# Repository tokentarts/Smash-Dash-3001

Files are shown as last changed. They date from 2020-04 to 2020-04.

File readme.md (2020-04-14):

# Smash Dash 3000

_By: Summer_

Smash Dash 3000 (https://www.youtube.com/watch?v=m0qOhI8Xyro "Smash Dash 3000")

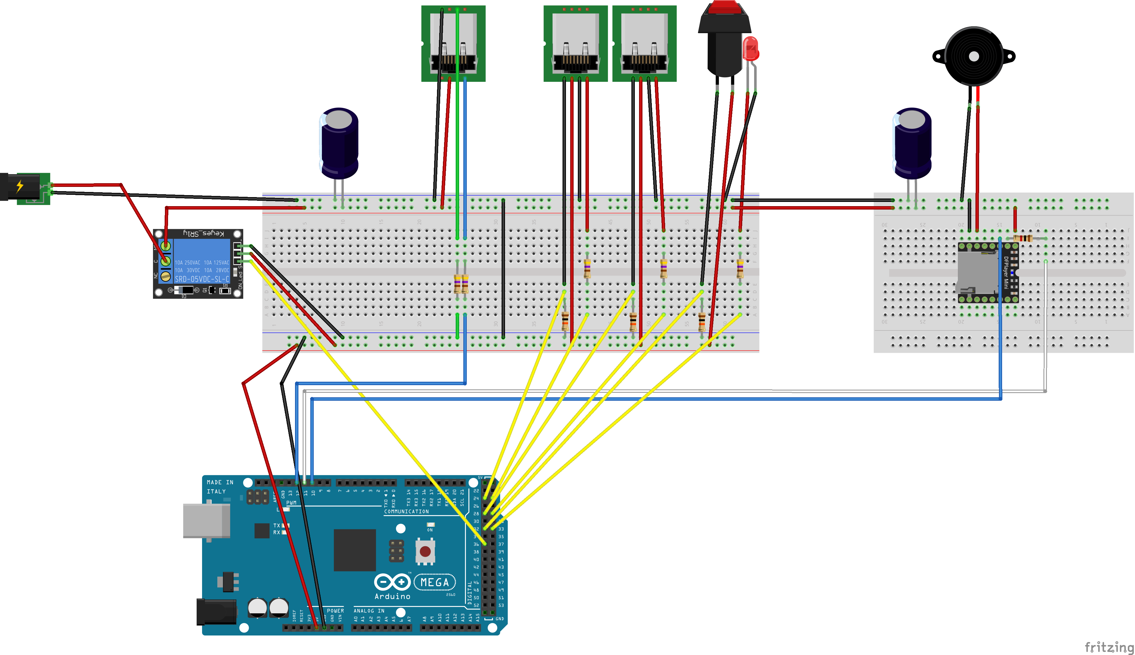
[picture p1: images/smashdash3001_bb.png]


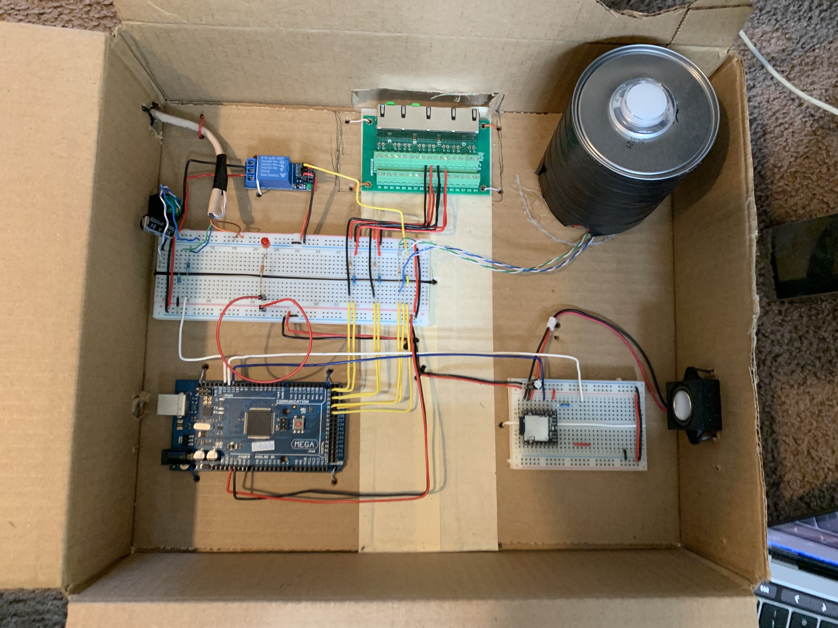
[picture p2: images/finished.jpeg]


This is a project about lights. I built an arduino based racing game involving smashing a button and racing to the end of an LED strip. There are added mechanics like gravity to make the game more exciting.

Shoutout to the inspiration for this project, [Open LED Race](https://create.arduino.cc/projecthub/gbarbarov/open-led-race-a0331a).

## Supplies

- Arduino Mega
- 5V Relay
- 5V 2.5A Power Supply
- WS2813 Led Strip 60 LED/5 Meter
- DF Player Mini
- RJ45 4-Port Breakout Board
- RJ45 Keystone (1)
- RJ45 Breakout (2)
- 1000 uF Capacitor
- 470 uF Capacitor
- 470 Ohm Resistor (5)
- 1000 Ohm Resistor
- 10k Ohm Resistor (3)
- Cardboard Box
- 3 Watt Speaker
- Pringles Can
- Empty Pill Bottle (2)
- 22 AWG Solid Wire
- Ethernet Cable
- Male RJ45 Connectors
- Breadboard
- Arcade Button (3)
- Micro SD

### Other things you'll need

- Micro SD Reader
- Wire Stripper
- RJ45 Crimper
- Soldering Iron
- Solder
- Shrinktube

## 1. Arduino and LED

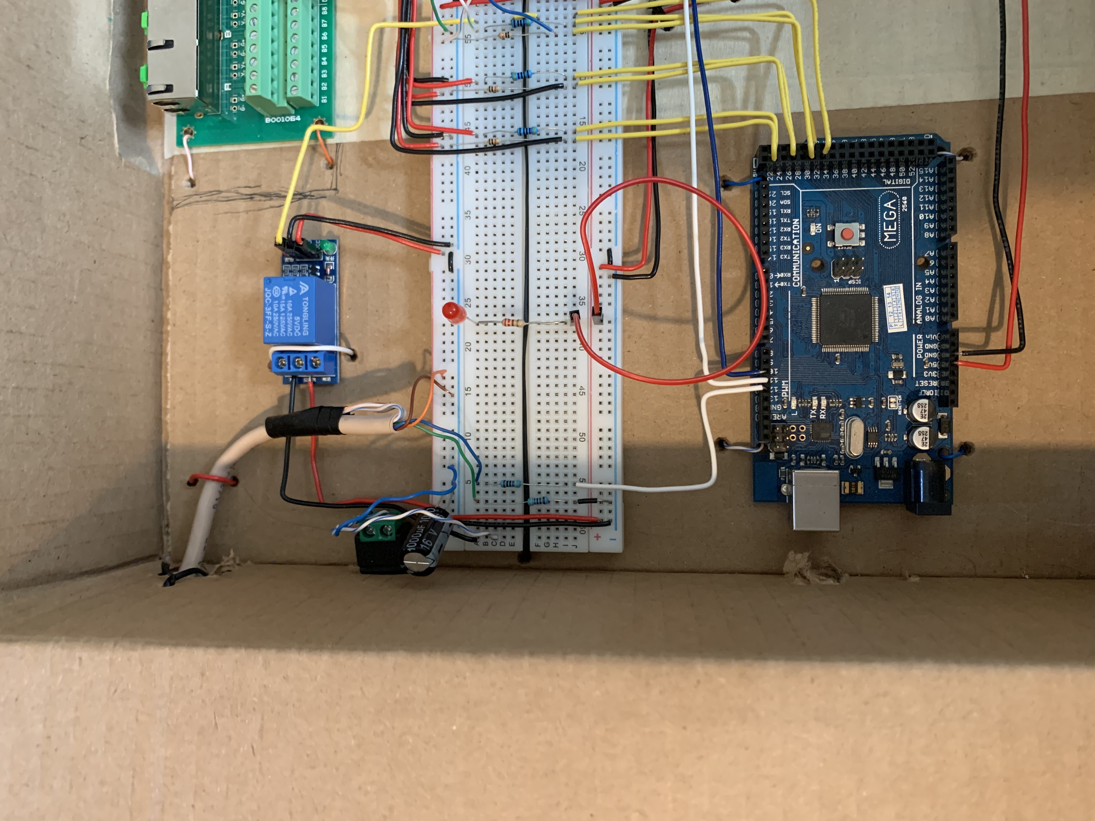
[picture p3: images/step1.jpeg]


### 1.1 Set up box

#### 1.1.1

Attach to your box: Arduino Mega, breadboard, relay, RJ45 plug, power supply plug

#### 1.1.2

Plug Arduino into breadboard (refer to wiring schematic).

#### 1.1.3

Plug relay into breadboard (refer to wiring schematic).

#### 1.1.4

RJ45 to breadboard, add resistors

Green = Back-up Data Line </br>
Blue = Data Line </br>
Orange = 5V </br>
Brown = Ground

Add a 470 Ohm resistor on both data line (refer to wiring schematic).

#### 1.1.5

Plug power supply into breadboard, add 1000 uF capacitor.

### 1.2 Set up LED strip

#### 1.2.1 Build LED extension wire

About 6-9 feet in length.

Solder wire connections.

Red (5V) = Orange </br>
Black (Ground) = Brown </br>
Yellow (Data) = Blue </br>
Green (Back-up Data) = Green

Use heat shrink.



#### 1.2.2 Tape LED wire leads

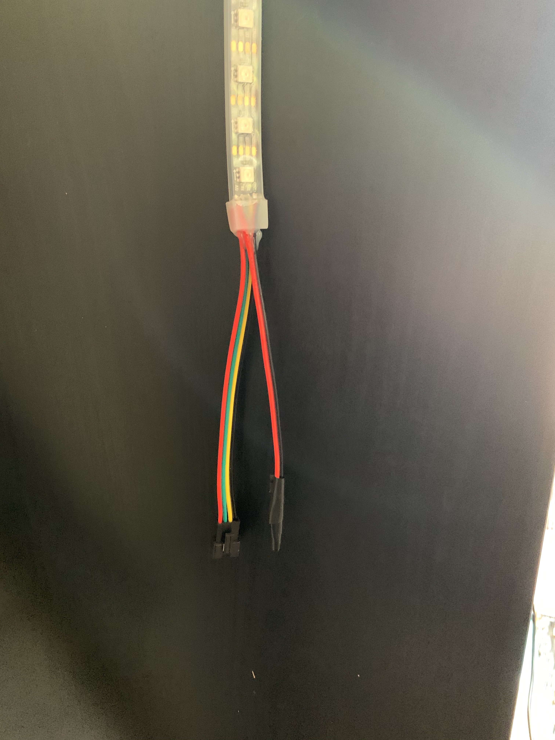
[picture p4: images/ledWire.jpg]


#### 1.2.3 Plug LED strip into RJ45 keystone.

### 1.3 Software: Turn on lights

See [`./code/step1-turnOnLights.ino`](./code/step1-turnOnLights.ino)

## Step 2: Start Button

### 2.1

Saw can half an inch inch taller than your box.

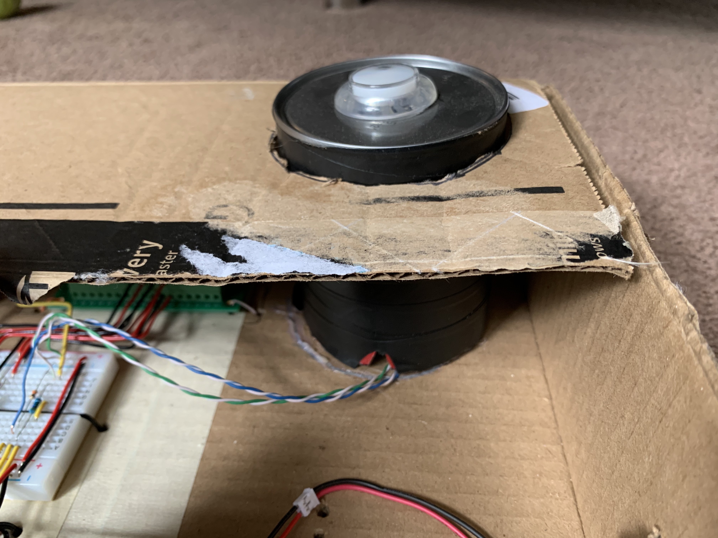
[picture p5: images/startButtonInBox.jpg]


### 2.2

Cut a hole for your arcade button.

Solder lead wires to start button.

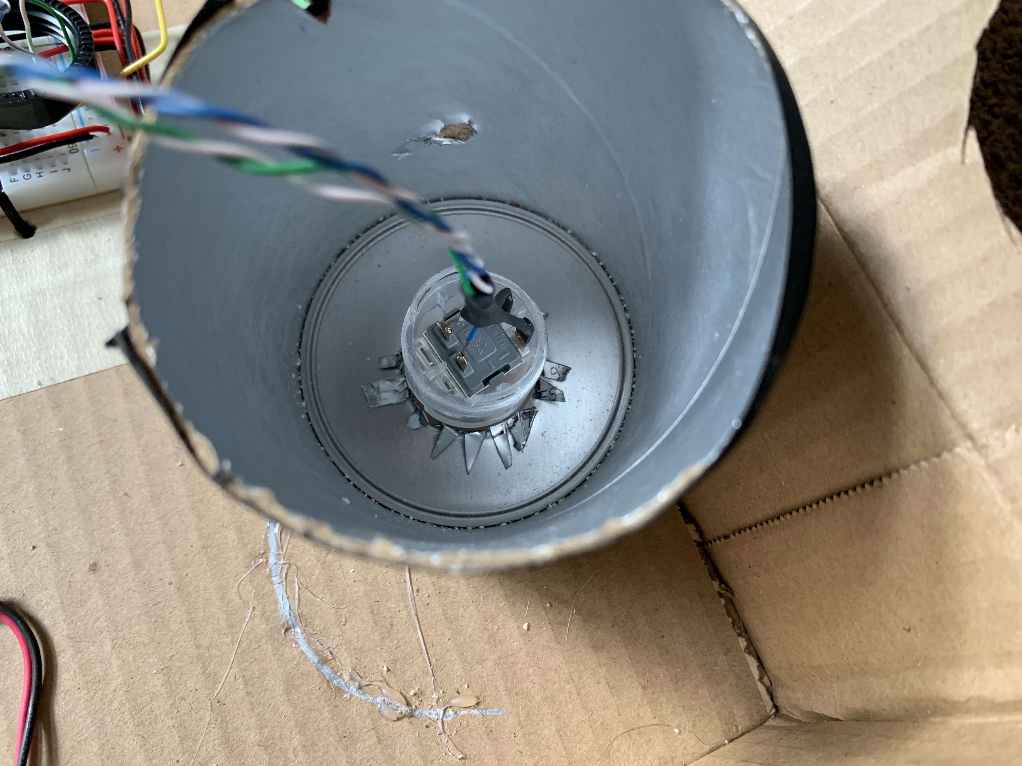
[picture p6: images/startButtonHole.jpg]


### 2.3

Connect start button lead wires to breadboard, and connect breadboard to Arduino.

Add 470 oHm resistor for LED.
Add 10k resistor for button.

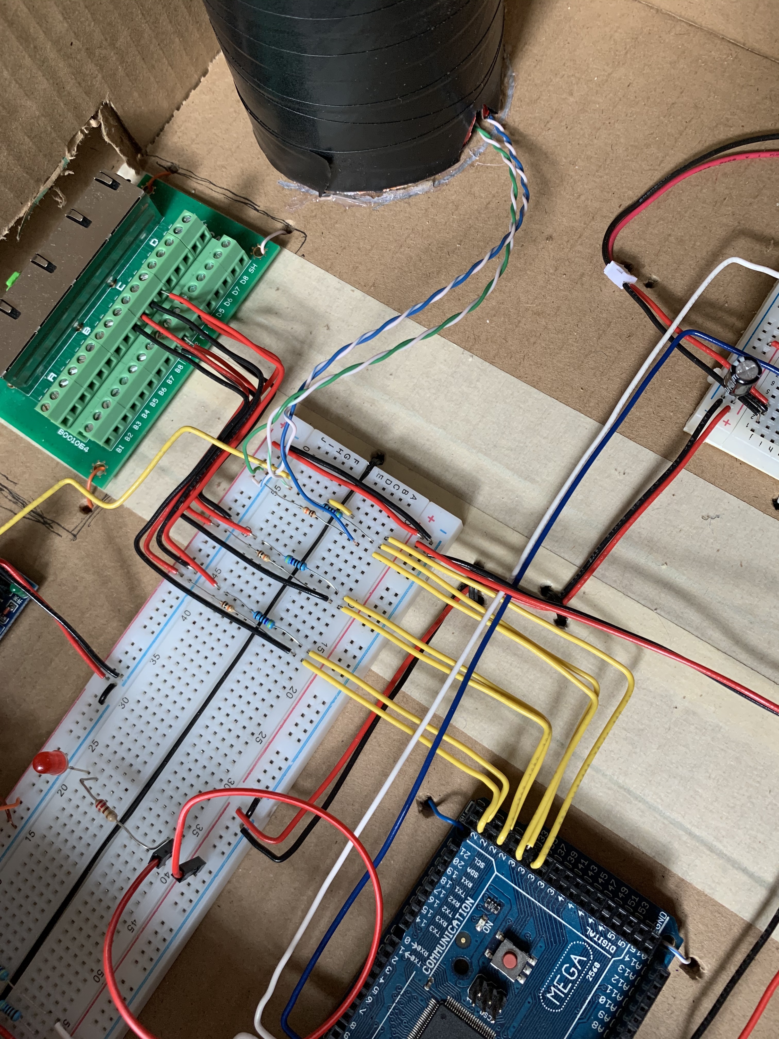
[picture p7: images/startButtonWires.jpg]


### 2.4 Software: Moving Lights

See [`./code/step2-movingLights.ino`](./code/step2-movingLights.ino)

## Step 3: Controllers

### 3.1 Connect controller breakout board to arduino

#### 3.1.1 First controller

This is the configuration for the first player controller. All wires should be connected to breakout board port `D`.

Controller breakout port wire configuration:

- Wire 1: +5 volt return from leg 2 of switch
  - Connect to an available terminal strip on breadboard
  - Connect a 10k ohm resistor from this terminal strip to ground. This ground reference helps avoid false positive readings.
- Wire 2: +5 volt going to leg 1 of switch
  - Connect to +5 volt power rail on breadboard
- Wire 3: Ground for button LED
  - Connect to -5 volt power rail on breadboard
- Wire 4: +5 volt signal for button LED
  - Connect to an available terminal strip on breadboard
  - Connect arduino to the opposing terminal strip
  - Connect the two terminal strips with a 470 ohm resistor

Player 1 button = pin 26 </br>
Player 1 LED = pin 27

#### 3.1.2 Second controller

Follow the steps for the first controller, except this time using breakout port `C`.

Player 2 button = pin 22 </br>
Player 2 LED = pin 23

### 3.2 Make an ethernet cable

About 6-9 feet in length.



### 3.2

Drill a hole in the bottom of the pill container.

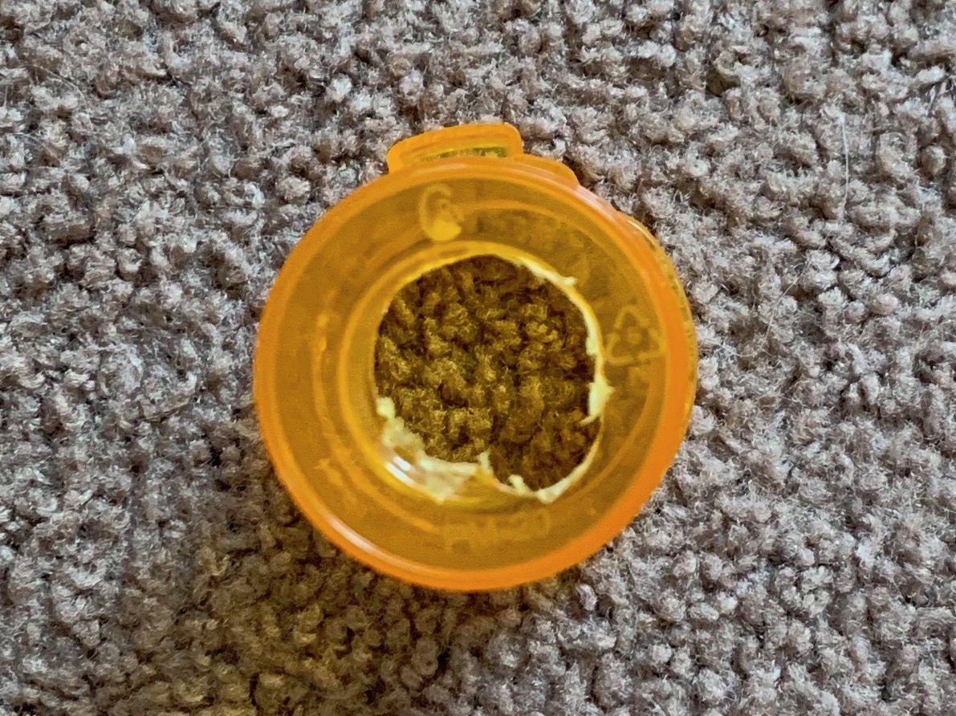
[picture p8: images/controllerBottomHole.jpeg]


### 3.3 Controller Top Assembly

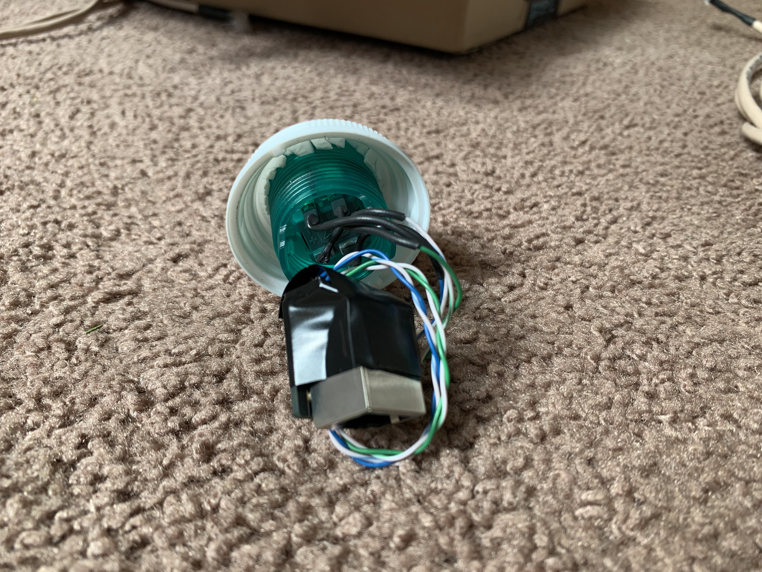
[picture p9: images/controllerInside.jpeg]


#### 3.3.1

Cut a hole in the lid of the pill container for the arcade button.

#### 3.3.2

Solder lead wires for your arcade button.

#### 3.3.3

Put your arcade button into the lid of the pill container.

#### 3.3.4

Attach the RJ45 Female breakout on the other side of the lid.

### 3.4 Controller Bottom Assembly

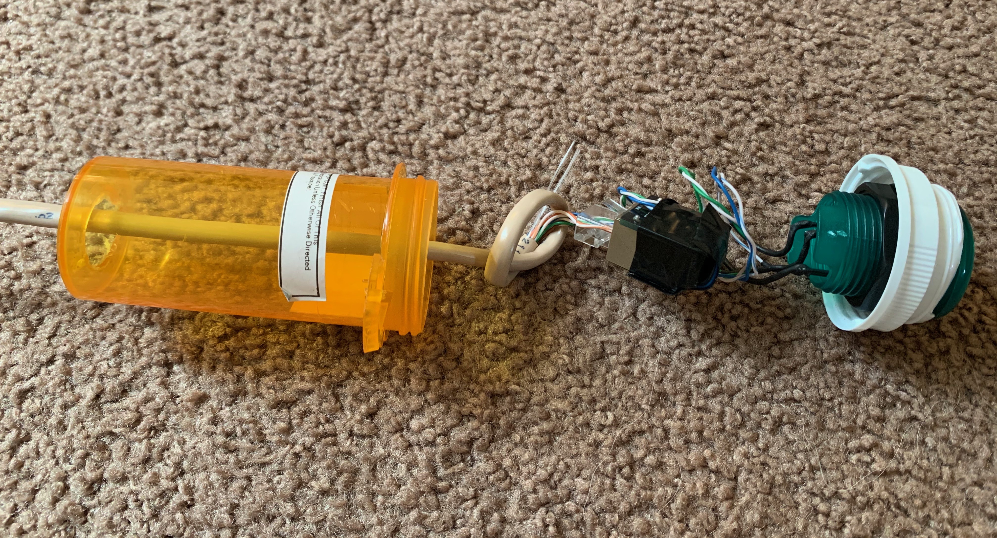
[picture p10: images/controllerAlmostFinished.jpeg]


Insert the ethernet cord into the bottom of the pill container, then tie a loose knot immediately below the end of the ethernet cord.

### 3.5 Controller Final Assembly

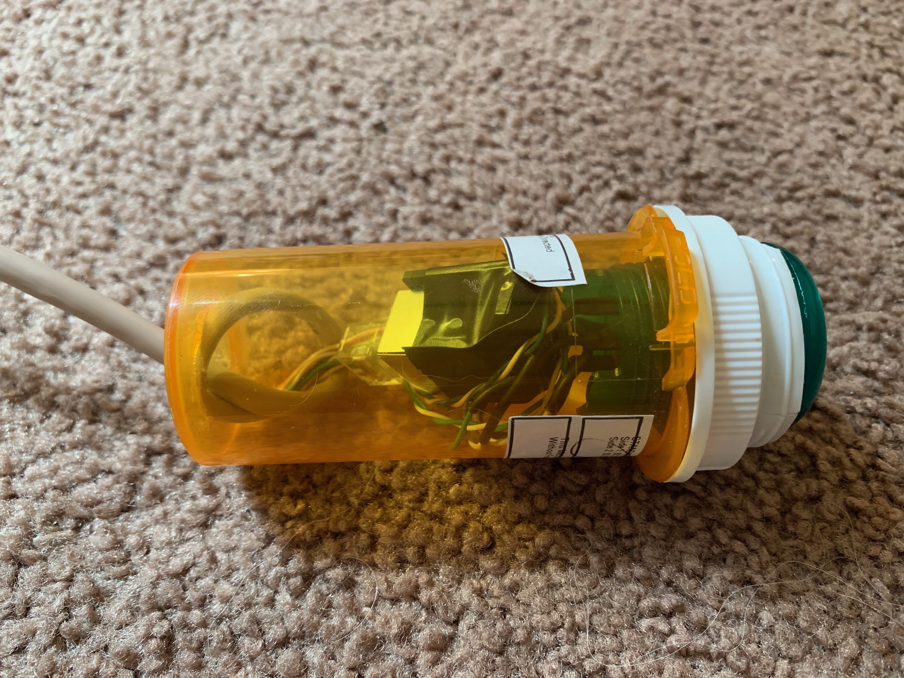
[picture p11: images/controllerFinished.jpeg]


Plug ethernet into RJ45 Female breakout. Be careful when you close container not to bend button pins.

### 3.6 Repeat for second controller

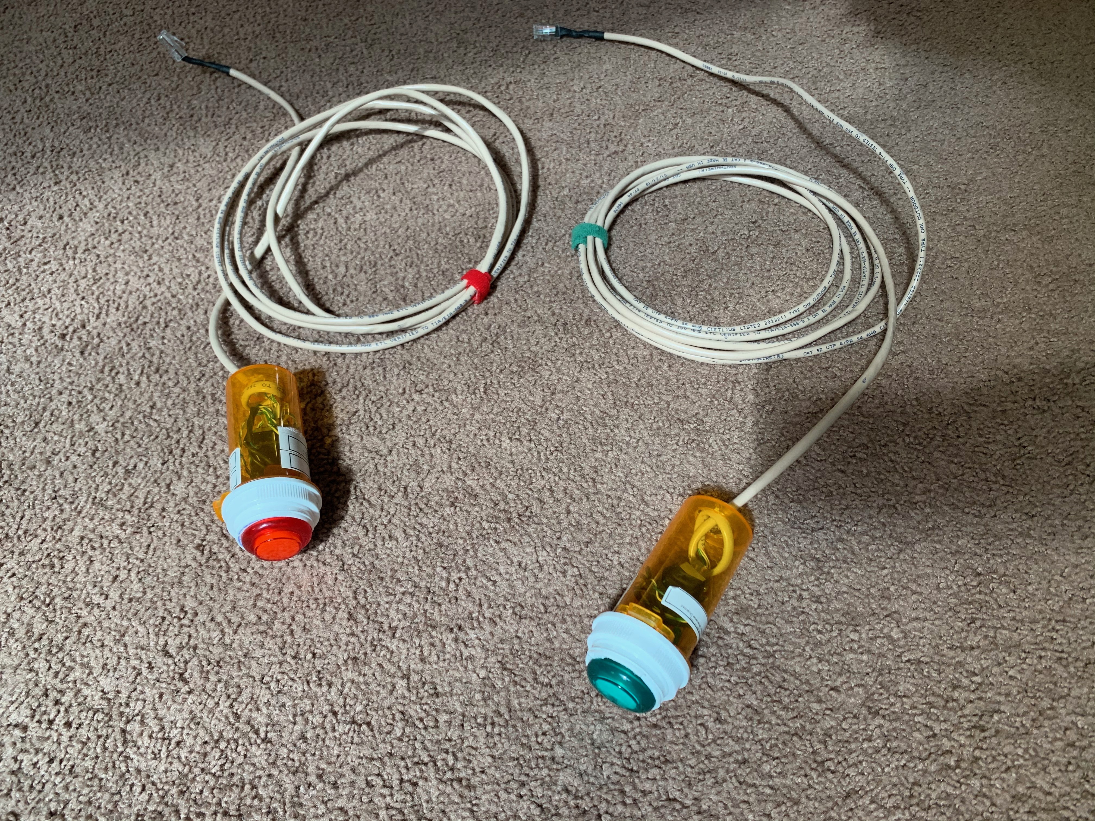
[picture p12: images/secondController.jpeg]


### 3.7 Software: Player Controls

See [`./code/step3-playerControls.ino`](./code/step3-playerControls.ino)

## Step 4: Audio

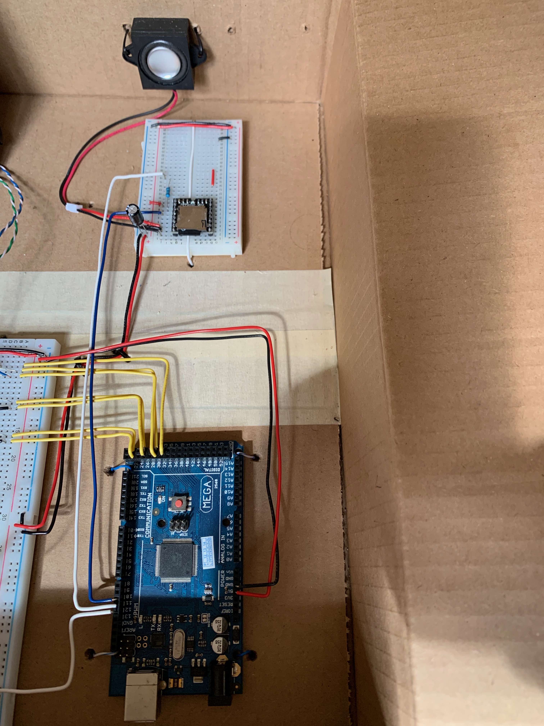
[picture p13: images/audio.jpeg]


### 4.1 Plug DF Player into breadboard

Add capacitor and resistor.

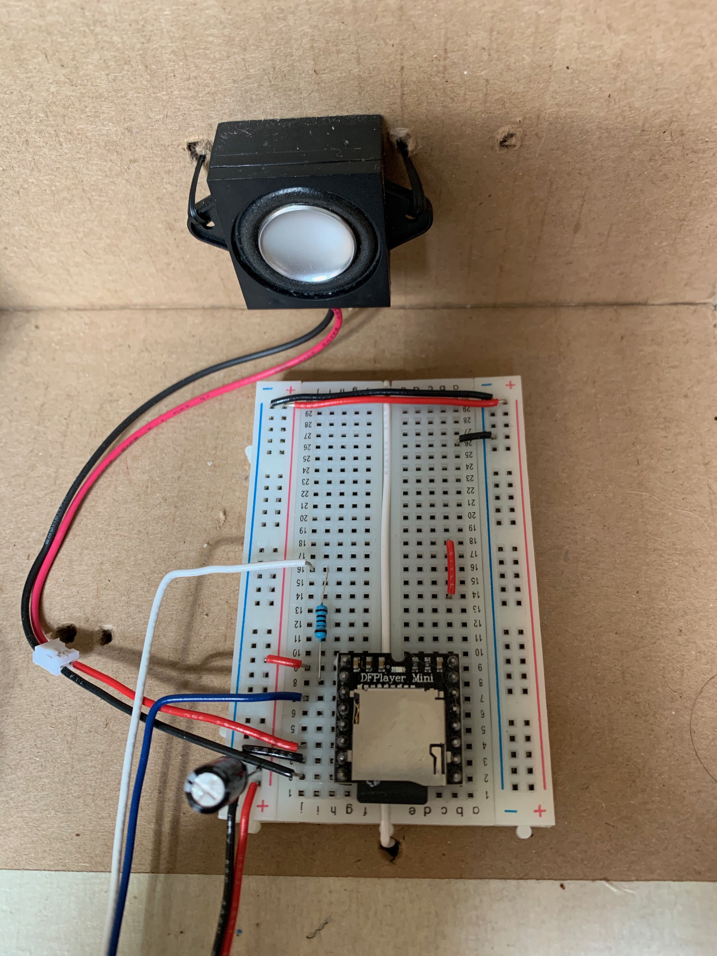
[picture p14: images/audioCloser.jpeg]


### 4.2 Plug 3 watt speaker into breadboard

### 4.3 Download sounds on to Micro SD

>The folder name needs to be mp3, placed under the SD card root directory, and the mp3 file name needs to be 4 digits, for example, "0001.mp3", placed under the mp3 folder. If you want to name it in Both English and Chinese, you can add it after the number, for example, "0001hello.mp3" or "0001后来.mp3".

See [`./audio/](./audio).

### 4.4 Plug Micro SD into DF Player

### 4.5 Software: Audio

See [`./code/step4-audio.ino`](./code/step4-audio.ino)

## Step 5: Gravity

### 5.1 Measure

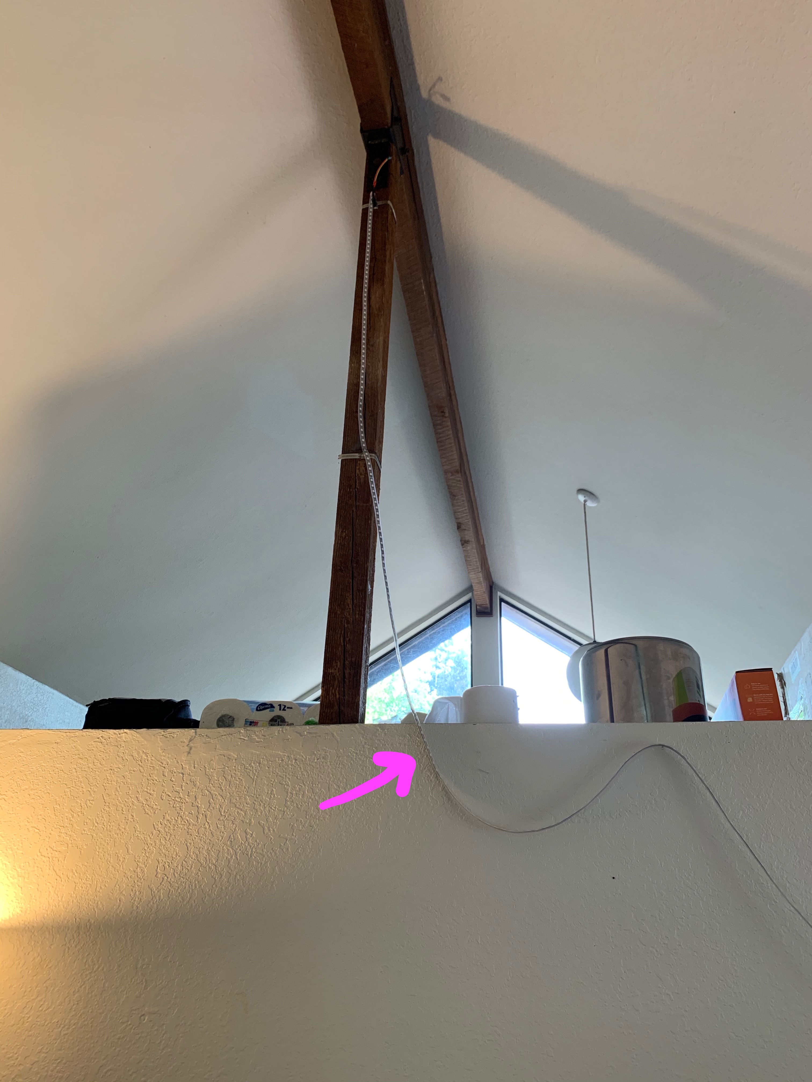
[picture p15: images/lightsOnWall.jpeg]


Hang your LED strip up on a wall or something. Choose a place that makes sense for gravity to begin, for example where the light strip begins traveling vertically.

Measure how far from the end of the LED strip this location is. Calculate the index of the LED at this position by using the measured length, the total length of the strip, and the distance between LEDs.

### 5.2 Software: Gravity time

See [`./code/step5-gravity.ino`](./code/step5-gravity.ino)

## Step 6: Final software

Add a winner to the game.

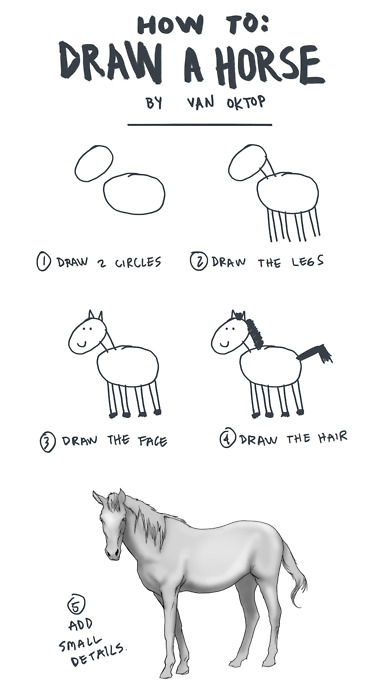
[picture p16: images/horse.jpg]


See [`./code/step6-final.ino`](./code/step6-final.ino)

## Step 7: Find a friend to compete with \o/

```txt
                        ██████        ██████████          ██████                        
                      ████████████████          ███████████████████                     
                    ████████████                        ████████████                    
                  ████████████                            ████████████                  
                  ██████████                                ██████████                  
                  ████████                                    ████████                  
                    ████        ██████            ██████        ████                    
                      ██      ████████            ████████      ██                      
                      ██    ██████  ██            ██  ██████    ██                      
                      ██    ██████████            ██████████    ██                      
                      ██    ██████████  ████████  ██████████    ██                      
                        ██  ████████    ████████    ████████  ██                        
                        ██    ████                    ████    ██                        
                          ██                                ██                          
                            ██                            ██                            
                              ████                    ████                              
                                ████████████████████████                                
                                ████████        ████████                                
                                ██  ████        ████  ██                                
                                ██                    ██                                
                                ██                    ██                                
                                  ████████████████████                                  
                                  ██████        ██████                                  
                                    ████        ████                                    
```

## Future Work

- [ ] Gravity contour
  - Right now gravity starts at a single point and remains on
  - Cooler to have multiple high and low portions, or have the strength of gravity change
- [ ] Make sure library imports are correct
  - Not sure if they are currently imported from project or global libraries directory
- [ ] 4 Players
  - Update code and wiring
- [ ] Use DFPlayer trigger pins
  - This will reduce use of software serial, increasing performance and audio responsiveness
  - Possible because there are two trigger ports and two sounds in our game lol
- [ ] Optimize parts list
  - Can probably make the parts list more simple and cheap
  - "Replace all female RJ45 with keystones"
- [ ] Use pullup input for controller
  - The current controller implementation uses normal input mode
  - https://www.arduino.cc/en/Tutorial/InputPullupSerial
  - This will allow the controller switch to share ground, reducing number of used wires back to the Arduino
- [ ] Dynamic player count
  - Code should use lists to dynamically handle any number of players
- [ ] Controller vibrators
  - Investigate how to connect vibrator motor without killing arduino or vibrator motor
  - Trial run with motor on breadboard
  - Install motor in pill bottle (Hot glue? Tape?)
- [ ] Taser mode
  - Investigate how to charge the taser transformer using arduino
  - Carefully plan installation: The high voltage released from the transformer will fry any of the existing components.
  - Install foil around a controller: half panels or quarter panels?
- [ ] Automatically detect connected players, and detect which position they are plugged in to
  - Use different resistors to identify controllers?

## Notes

### Light strip power delivery

With 24/4 cat 5e cable we see significant voltage drop at the end of the deployed LED strip. Adding a 3300uF capacitor at the top end does not improve the situation beyond a millisecond or so.

Voltage drop can be observed as color drift at the end of strip while entire strip is on. If the color should be white, led[0] is white, and led[300] is red.

Issue seems to be with the current available to the LED strip.

Amazon reviews for the 15A power supply we are using suggest its working load is closer to 3A.

Current required for LED strip:
- 300 LEDs
- Max bright 60ma per LED (found on random forum post)
- 300 * 60 = 18,000mA
- Power draw per foot:
  - LED per foot: 300 / 16.4= 18.3
  - Theoretical consumption: 18.3 * 60 = 1.1A

Observed:
- At constant 100 brightness
- Theoretical consumption: 300 * ((100 / 255) * 60) = 7.1A
- Power supply from amazon delivers a max of around 2.5A
- Desktop supply delivers a max of around 3.5A
- After a couple minutes at this, the base of the LED strip was starting to warm up

Seems like the LED strip cannot power itself at full brightness without starting to lose power to heat. This seems particularly bad, given the LED strip is soldered together sheets of flexible PCB.

FastLED has a power management API, which should limit the brightness of a `.show()` call based on the expected power consumption.

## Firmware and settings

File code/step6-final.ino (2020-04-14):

#pragma message "SUMMER'S SMASH DASH 3000 PROJECT FT. JJ BROWN\nOriginal implementation in Smash-Dash-3000/code/step6-final"

// #region Imports

#include "Arduino.h"

// #region FastLED Import

// Add this before including `FastLED.h` to quiet pragma messages
#define FASTLED_INTERNAL

// Use this to import the library from project subdirectory.
// Note: This fails with VSCode Arduino compilation.
//#include "libraries/FastLED-3.3.3/FastLED.h"

// Use this import to include the global FastLED library
//   located at `~/Documents/Arduino/libraries/FastLED-3.3.3/`.
#include <FastLED.h>

// #endregion FastLED Import

#include <SoftwareSerial.h>
// #include "libraries/DFRobotDFPlayerMini/DFRobotDFPlayerMini.h"
#include <DFRobotDFPlayerMini.h>

// #endregion Imports

// #region Constant Variables

// Use `#define` for constant variables to leverage compiler optimization

// Set this to false for performance improvements:
// - Fewer calls to `Serial` to log debugging values
// - Fewer diagnostic calls to connected peripherals
#define IS_DEVELOPMENT false
#define ENABLE_LOGS false

// This is the signal pin for the main power relay
#define POWER_RELAY_PIN 32

// ---- Sound ----

// Value range (0~30)
#define MP3_VOLUME (IS_DEVELOPMENT ? 15 : 28)

#define MP3_START_SOUND 1
#define MP3_BOOP_SOUND 2

#define MIN_BOOP_DELAY 300

// ---- Start Controls ----

// The pin that the start button switch is attached to
#define START_BUTTON_PIN 30
// The pin for start button LED
#define START_BUTTON_LED_PIN 31

// ---- Player Controls ----

// Player 1
#define BUTTON_PIN_ONE 26
#define BUTTON_LED_PIN_ONE 27
// Player 2
#define BUTTON_PIN_TWO 22
#define BUTTON_LED_PIN_TWO 23

// ---- Lights ----

#define NUM_LEDS 300
#define LED_STRING_DATA_PIN 12

// Render player position
#define MAX_DISTANCE_TO_PLAYER 2.0

// Note: Milliamp value determined experimentally.
// - 3500mA works well if the 15A power supply is connected directly to one
//   end of the LED strip.
// - 1850mA works well if the LED strip is powered through breadboard and
//   jumper wires
#define LED_MAX_MILLIAMPS 1850

// Maximum brightness displayed by any LED
#define LED_MAX_POWER (IS_DEVELOPMENT ? 200 : 240)

// ---- Game ----

#define MIN_PLAYER_POSITION 0
#define MAX_PLAYER_POSITION NUM_LEDS

// Magic number: Tune this based on your own gameplay
#define PLAYER_VELOCITY_PICKUP 0.11

// Maximum player speed is ~32 presses of controller button
#define MAX_PLAYER_VELOCITY (32 * PLAYER_VELOCITY_PICKUP)

// Magic number: Tune this based on your own gameplay
#define FRICTION .96

// The index of the LED on the strip where gravity should start being applied
#define GRAVITY_START 210

// Magic number: Tune this based on your own gameplay
#define GRAVITY_AMOUNT 0.022

// ---- State Machine ----

#define STATE_NOT_LOADED -1
#define STATE_START_MENU 0
#define STATE_RESET_GAME 1
#define STATE_321_COUNTDOWN 2
#define STATE_GAMEPLAY 3
#define STATE_FINISH_LINE 4

// #endregion Constant Variables

// #region Global Variables

// ---- Sound ----

// The last time (in milliseconds) that a sound was played.
// The DFPlayer can only play a single sound at once, so rapid calls to start
//   playing a sound result in never hearing more than the first few seconds of
//   the audio clip.
unsigned long lastBoopTime = 0;

// The SoftwareSerial is used to communicate with the DFPlayer.
// Argument order is (RX Pin, TX Pin)
SoftwareSerial mySoftwareSerial(10, 11);
DFRobotDFPlayerMini myDFPlayer;

// ---- Lights ----

// Create an array of `CRGB` instances.
// Each item in the array specifies the color for a given LED on the strip.
// Each item in the array holds a red, green, and blue value.
CRGB leds[NUM_LEDS];

// ---- Game ----

// The current state for start button
// 0 for not pressed, 1 for pressed.
byte lastStartButtonState = 0;
// The previous state of the start button.
byte startButtonState = 0;

// The current state of each controller.
byte playerButtonStateOne = 0;
byte playerButtonStateTwo = 0;

byte lastPlayerButtonStateOne = 0;
byte lastPlayerButtonStateTwo = 0;

unsigned long lastStartButtonLedBlinkTime = 0;

// In the game each player moves from the start to the end of the LED strip.
float playerPositionOne = 0;
float playerPositionTwo = 0;

// When a player controller is pressed, that player velocity is increased.
// Player velocity is applied to player position once per `loop()` call.
float playerVelocityOne = 0;
float playerVelocityTwo = 0;

// These variables store the color to display for each player
// 1: Red
const CRGB playerColorOne = CRGB(200, 0, 0).fadeToBlackBy(IS_DEVELOPMENT ? 128 : 0);
// 2: Green
const CRGB playerColorTwo = CRGB(9, 227, 67).fadeToBlackBy(IS_DEVELOPMENT ? 128 : 0);

byte winnerIndex = 0;
CRGB *winnerColor;
unsigned int finishLineAnimationStep = 0;
unsigned long finishLineLastAnimationStepTime = 0;

// ---- State Machine ----

byte currentState = STATE_NOT_LOADED;

// #endregion Global Variables

// #region State Machine Functions

void setState(int newState)
{
  int lastState = currentState;
  if (ENABLE_LOGS)
  {
    Serial.print("setState: newState= ");
    Serial.print(newState);
    Serial.print(" lastState= ");
    Serial.print(lastState);
    Serial.print("\n");
  }

  currentState = newState;

  // Transition between states

  // Transition FROM
  if (lastState == STATE_START_MENU)
  {
    transitionFromStartMenu();
  }

  // Transition TO
  if (currentState == STATE_321_COUNTDOWN)
  {
    transitionTo321Countdown();
  }
  else if (currentState == STATE_RESET_GAME)
  {
    transitionToResetGame();
  }
  else if (currentState == STATE_GAMEPLAY)
  {
    transitionToGameplay();
  }
  else if (currentState == STATE_FINISH_LINE)
  {
    transitionToFinishLine();
  }
}

void transitionToFinishLine()
{
  // Turn off all controller lights, leave winner on
  if (winnerIndex == 0)
  {
    digitalWrite(BUTTON_LED_PIN_ONE, LED_MAX_POWER);
    digitalWrite(BUTTON_LED_PIN_TWO, LOW);
  }
  else if (winnerIndex == 1)
  {
    digitalWrite(BUTTON_LED_PIN_ONE, LOW);
    digitalWrite(BUTTON_LED_PIN_TWO, LED_MAX_POWER);
  }
}

void transitionFromStartMenu()
{
  digitalWrite(START_BUTTON_LED_PIN, LOW);
}

/** Auto transition to STATE_GAMEPLAY */
void transitionTo321Countdown()
{
  // Play sound
  myDFPlayer.playMp3Folder(MP3_START_SOUND);

  // Wait for start sound to end
  delay(1000);

  setState(STATE_GAMEPLAY);
}

void transitionToGameplay()
{
  FastLED.clear();
}

/**
 * Reset all gameplay related variables.
 * Auto transition to STATE_START_MENU
 */
void transitionToResetGame()
{
  // Reset player state
  playerButtonStateOne = 0;
  lastPlayerButtonStateOne = 0;
  playerButtonStateTwo = 0;
  lastPlayerButtonStateTwo = 0;

  startButtonState = 0;
  lastStartButtonState = 0;

  playerPositionOne = 0;
  playerPositionTwo = 0;
  playerVelocityOne = 0;
  playerVelocityTwo = 0;

  winnerIndex = 0;
  winnerColor = nullptr;
  finishLineAnimationStep = 0;
  finishLineLastAnimationStepTime = 0;

  // Stop all audio
  myDFPlayer.pause();

  setState(STATE_321_COUNTDOWN);
}

// #endregion State Machine Functions

// #region Sound Functions

/**
 * This function will repeatedly attempt to establish a serial connection with
 * the DFPlayer. A single attempt infrequently fails. This guarantees a
 * consistent user experience.
 */
void waitForMp3Connection()
{
  if (ENABLE_LOGS)
    Serial.print("\nInitializing DFPlayer ... (May take 3~5 seconds)\n");

  int connectionTryCount = 0;

  while (true)
  {
    connectionTryCount++;

    if (ENABLE_LOGS)
    {
      Serial.print("Attempting connection to MP3 player... connectionTryCount= ");
      Serial.print(connectionTryCount);
      Serial.print("\n");
    }

    bool isMp3PlayerConnected = myDFPlayer.begin(mySoftwareSerial);

    if (!isMp3PlayerConnected)
    { //Use softwareSerial to communicate with mp3.
      Serial.println("Unable to begin, connection to MP3 player failed:");
      Serial.println("1.Please recheck the connection!");
      Serial.println("2.Please insert the SD card!");

      Serial.println("Retrying...");
      delay(1000);
    }
    else
    {
      break;
    }
  }

  if (ENABLE_LOGS)
    Serial.println("DFPlayer Mini online.");
}

void playBoopSound(const unsigned long now)
{
  if (now - lastBoopTime > MIN_BOOP_DELAY)
  {
    lastBoopTime = now;

    myDFPlayer.playMp3Folder(MP3_BOOP_SOUND);
  }
}

// #endregion Sound Functions

// #region Setup Functions

void setupLights()
{
  FastLED.addLeds<NEOPIXEL, LED_STRING_DATA_PIN>(leds, NUM_LEDS);

  FastLED.clear();

  FastLED.setMaxPowerInVoltsAndMilliamps(5, LED_MAX_MILLIAMPS);
}

void setupAudio()
{
  // Start MP3 player serial connection
  // - `9600` is the baud rate of the connection
  mySoftwareSerial.begin(9600);

  // Initialize MP3 player
  waitForMp3Connection();

  myDFPlayer.reset();
  myDFPlayer.setTimeOut(500);
  myDFPlayer.volume(MP3_VOLUME);
  myDFPlayer.EQ(DFPLAYER_EQ_NORMAL);
  myDFPlayer.enableDAC();

  if (ENABLE_LOGS)
  {
    Serial.print("mp3 state = ");
    Serial.println(myDFPlayer.readState());

    Serial.print("current volume = ");
    Serial.println(myDFPlayer.readVolume());

    Serial.print("EQ setting = ");
    Serial.println(myDFPlayer.readEQ());

    Serial.print("all file counts in SD card = ");
    Serial.println(myDFPlayer.readFileCounts());

    Serial.print("current play file number = ");
    Serial.println(myDFPlayer.readCurrentFileNumber());
  }
}

/** Sets pin mode for player controller. */
void setupStartButton()
{
  // Ensure the correct pin modes for start button are set
  pinMode(START_BUTTON_PIN, INPUT);
  pinMode(START_BUTTON_LED_PIN, OUTPUT);
}

void setupUserInput()
{
  // Ensure the correct pin modes are set for player buttons
  pinMode(BUTTON_PIN_ONE, INPUT);
  pinMode(BUTTON_LED_PIN_ONE, OUTPUT);

  pinMode(BUTTON_PIN_TWO, INPUT);
  pinMode(BUTTON_LED_PIN_TWO, OUTPUT);
}

void setup()
{
  if (ENABLE_LOGS)
  {
    // Start serial connection over USB.
    // This is what shows up in the serial monitor (baud rate in monitor must
    // match argument here).
    Serial.begin(9600);
  }

  // Turn on main power relay
  pinMode(POWER_RELAY_PIN, OUTPUT);
  digitalWrite(POWER_RELAY_PIN, LOW);

  setupLights();

  // Waits for MP3 connection
  setupAudio();

  setupStartButton();

  setupUserInput();

  // Initialize player state
  setState(STATE_START_MENU);
}

// #endregion Setup Functions

// #region Miscellaneous Functions

/** @return Current value of start button LED pin. */
bool blinkStartButtonLed(const unsigned long now)
{
  bool startButtonLedState = digitalRead(START_BUTTON_LED_PIN);

  if (now - lastStartButtonLedBlinkTime > 500)
  {
    lastStartButtonLedBlinkTime = now;

    // Blink start button LED
    if (startButtonLedState == LOW)
    {
      // Turn LED on
      digitalWrite(START_BUTTON_LED_PIN, LED_MAX_POWER);
      return true;
    }
    else
    {
      // Turn LED off
      digitalWrite(START_BUTTON_LED_PIN, LOW);
      return false;
    }
  }

  return startButtonLedState;
}

void setWinner(byte newWinnerIndex)
{
  winnerIndex = newWinnerIndex;

  if (winnerIndex == 0)
  {
    winnerColor = &playerColorOne;
  }
  else if (winnerIndex == 1)
  {
    winnerColor = &playerColorTwo;
  }
  else
  {
    // If unknown winner, transition to reset
    if (ENABLE_LOGS)
    {
      Serial.print("Unknown winnerIndex:");
      Serial.println(winnerIndex);
    }
    setState(STATE_RESET_GAME);
    return;
  }

  setState(STATE_FINISH_LINE);
}

bool checkStartButtonState()
{
  // Check for start button press
  int startButtonState = digitalRead(START_BUTTON_PIN);

  if (startButtonState != lastStartButtonState)
  {
    lastStartButtonState = startButtonState;

    if (ENABLE_LOGS)
    {
      Serial.print("startButtonState= ");
      Serial.println(startButtonState);
    }

    if (startButtonState == HIGH)
    {
      return true;
    }
  }

  return false;
}

// #endregion Miscellaneous Functions

// #region State Machine Loop Functions

void loopStateStartMenu(
    const unsigned long now)
{
  if (checkStartButtonState())
  {
    setState(STATE_RESET_GAME);
    return;
  }

  bool startButtonLedState = blinkStartButtonLed(now);

  // Set all LED strip to same state as start button LED
  byte brightness = startButtonLedState ? LED_MAX_POWER * 0.5 : 0;
  CRGB color = CRGB(brightness, brightness, brightness);

  for (int lightIndex = 0; lightIndex < NUM_LEDS; lightIndex++)
  {
    leds[lightIndex] = color;
  }
}

void loopStateFinishLine(
    const unsigned long now)
{
  if (checkStartButtonState())
  {
    setState(STATE_START_MENU);
    return;
  }

  // Indicate how to reset game to user
  blinkStartButtonLed(now);

  // Finish Line animation: drip the color of the winner from end of strip to
  // start. Leave non-winner colors on strip for bragging rights.
  if (
      now - finishLineLastAnimationStepTime > 15 &&
      finishLineAnimationStep < NUM_LEDS)
  {
    finishLineLastAnimationStepTime = now;

    unsigned int currentLedIndex = NUM_LEDS - finishLineAnimationStep;

    if (leds[currentLedIndex].red == 0 &&
        leds[currentLedIndex].green == 0 &&
        leds[currentLedIndex].blue == 0)
    {
      leds[currentLedIndex] = *winnerColor;
    }

    finishLineAnimationStep++;
  }
}

void loopStateGameplay(unsigned long now, byte playerButtonStateOne, byte playerButtonStateTwo)
{
  // #region User Input: Player One
  if (playerButtonStateOne != lastPlayerButtonStateOne)
  {
    if (ENABLE_LOGS)
    {
      Serial.print("playerButtonStateOne= ");
      Serial.println(playerButtonStateOne);
    }

    // if the state has changed, increment the counter
    if (playerButtonStateOne == HIGH)
    {
      // if the current state is HIGH then the button
      // wend from off to on:
      playerVelocityOne = playerVelocityOne + PLAYER_VELOCITY_PICKUP;

      // CLAMP PLAYER VELOCITY
      if (playerVelocityOne > MAX_PLAYER_VELOCITY)
      {
        playerVelocityOne = MAX_PLAYER_VELOCITY;
      }

      playBoopSound(now);
    }

    // save the current state as the last state,
    //for next time through the loop
    lastPlayerButtonStateOne = playerButtonStateOne;
  }
  // #endregion

  // #region User Input: Player Two
  if (playerButtonStateTwo != lastPlayerButtonStateTwo)
  {
    if (ENABLE_LOGS)
    {
      Serial.print("playerButtonStateTwo= ");
      Serial.println(playerButtonStateTwo);
    }

    // if the state has changed, increment the counter
    if (playerButtonStateTwo == HIGH)
    {
      playerVelocityTwo = playerVelocityTwo + PLAYER_VELOCITY_PICKUP;

      // CLAMP PLAYER VELOCITY
      if (playerVelocityTwo > MAX_PLAYER_VELOCITY)
      {
        playerVelocityTwo = MAX_PLAYER_VELOCITY;
      }

      playBoopSound(now);
    }

    // save the current state as the last state,
    //for next time through the loop
    lastPlayerButtonStateTwo = playerButtonStateTwo;
  }
  // #endregion

  // Update player position
  playerPositionOne = playerPositionOne + playerVelocityOne;
  playerPositionTwo = playerPositionTwo + playerVelocityTwo;

  // APPLY FRICTION
  float lastPlayerVelocity = playerVelocityOne;
  playerVelocityOne = playerVelocityOne * FRICTION;

  float lastPlayerVelocityTwo = playerVelocityTwo;
  playerVelocityTwo = playerVelocityTwo * FRICTION;

  // Apply gravity
  // Note: Only check start of gravity, since end is end of LED strip.
  if (playerPositionOne > GRAVITY_START)
  {
    playerVelocityOne -= GRAVITY_AMOUNT;
  }

  if (playerPositionTwo > GRAVITY_START)
  {
    playerVelocityTwo -= GRAVITY_AMOUNT;
  }

  if (ENABLE_LOGS && floor(lastPlayerVelocity * 10) != floor(playerVelocityOne * 10))
  {
    Serial.print("playerVelocityOne= ");
    Serial.println(playerVelocityOne);
  }

  if (playerPositionOne >= MAX_PLAYER_POSITION)
  {
    playerPositionOne = MAX_PLAYER_POSITION;
    setWinner(0);
    return;
  }

  if (ENABLE_LOGS && floor(lastPlayerVelocityTwo * 10) != floor(playerVelocityTwo * 10))
  {
    Serial.print("playerVelocityTwo= ");
    Serial.println(playerVelocityTwo);
  }

  if (playerPositionTwo >= MAX_PLAYER_POSITION)
  {
    playerPositionTwo = MAX_PLAYER_POSITION;
    setWinner(1);
    return;
  }
}

// #endregion State Machine Loop Functions

// #region Render Functions

/** Update player feedback based on player controller state. */
void renderPlayerButtons(
    byte playerButtonStateOne, byte playerButtonStateTwo)
{
  if (playerButtonStateOne == LOW)
  {
    digitalWrite(BUTTON_LED_PIN_ONE, LOW);
  }
  else
  {
    digitalWrite(BUTTON_LED_PIN_ONE, LED_MAX_POWER);
  }

  if (playerButtonStateTwo == LOW)
  {
    digitalWrite(BUTTON_LED_PIN_TWO, LOW);
  }
  else
  {
    digitalWrite(BUTTON_LED_PIN_TWO, LED_MAX_POWER);
  }
}

/** Render player positions on LED strip. */
void renderPlayerPositions()
{
  for (int lightIndex = 0; lightIndex < NUM_LEDS; lightIndex++)
  {
    // Player 1
    float distanceToPlayer = fabs(playerPositionOne - (float)lightIndex);
    if (distanceToPlayer > MAX_DISTANCE_TO_PLAYER)
    {
      distanceToPlayer = MAX_DISTANCE_TO_PLAYER;
    }

    float lightPowerPercent = (MAX_DISTANCE_TO_PLAYER - distanceToPlayer) / MAX_DISTANCE_TO_PLAYER;

    byte red = playerColorOne.red * lightPowerPercent;
    byte green = playerColorOne.green * lightPowerPercent;
    byte blue = playerColorOne.blue * lightPowerPercent;

    // if (ENABLE_LOGS && lightPower > 0) {
    //   Serial.print("Light status: index= ");
    //   Serial.print(lightIndex);
    //   Serial.print(" distanceToPlayer= ");
    //   Serial.print(distanceToPlayer);
    //   Serial.print(" power= ");
    //   Serial.print(lightPower);
    //   Serial.print("\n");
    // }

    // Player 2
    float distanceToPlayerTwo = fabs(playerPositionTwo - (float)lightIndex);

    if (distanceToPlayerTwo > MAX_DISTANCE_TO_PLAYER)
    {
      distanceToPlayerTwo = MAX_DISTANCE_TO_PLAYER;
    }

    float lightPowerPercentTwo = (MAX_DISTANCE_TO_PLAYER - distanceToPlayerTwo) / MAX_DISTANCE_TO_PLAYER;

    // Note: Use `+=` to add player two brightness to player one brightness.
    red += playerColorTwo.red * lightPowerPercentTwo;
    green += playerColorTwo.green * lightPowerPercentTwo;
    blue += playerColorTwo.blue * lightPowerPercentTwo;

    // Clamp light max value
    if (red > LED_MAX_POWER)
    {
      red = LED_MAX_POWER;
    }
    if (green > LED_MAX_POWER)
    {
      green = LED_MAX_POWER;
    }
    if (blue > LED_MAX_POWER)
    {
      blue = LED_MAX_POWER;
    }

    leds[lightIndex].red = red;
    leds[lightIndex].green = green;
    leds[lightIndex].blue = blue;
  }
}

// #endregion Render Functions

void loop()
{
  unsigned long now = millis();

  if (currentState == STATE_GAMEPLAY)
  {
    // Check for player button press
    byte playerButtonStateOne = digitalRead(BUTTON_PIN_ONE);
    byte playerButtonStateTwo = digitalRead(BUTTON_PIN_TWO);

    // Update game state
    loopStateGameplay(now, playerButtonStateOne, playerButtonStateTwo);

    // Display game state to user
    renderPlayerButtons(playerButtonStateOne, playerButtonStateTwo);
    renderPlayerPositions();
  }
  else if (currentState == STATE_START_MENU)
  {
    loopStateStartMenu(now);
  }
  else if (currentState == STATE_FINISH_LINE)
  {
    loopStateFinishLine(now);
  }

  // Send 'leds' data from arduino to led strip.
  // Should call once per `loop`.
  FastLED.show();
}

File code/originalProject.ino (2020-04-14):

#pragma message "SUMMER'S SMASH DASH 3000 PROJECT FT. JJ BROWN"

#include "Arduino.h"
#include "SoftwareSerial.h"
// #include "libraries/DFRobotDFPlayerMini/DFRobotDFPlayerMini.h"
#include <DFRobotDFPlayerMini.h>

#define FASTLED_INTERNAL // add this before including FastLED.h
//#include "libraries/FastLED-3.3.3/FastLED.h"
#include <FastLED.h>

// #region Config

// Set this to false for performance improvements:
// - Fewer calls to `Serial` to log debugging values
// - Fewer diagnostic calls to connected peripherals
#define IS_DEVELOPMENT false
#define ENABLE_LOGS false

// ---- Sound ----

// const bool ENABLE_SOUND = false;

#define MP3_POWER_RELAY_PIN 32

// Value range (0~30)
#define MP3_VOLUME (IS_DEVELOPMENT ? 15 : 25)

#define MP3_START_SOUND 1
#define MP3_BOOP_SOUND 2

#define MIN_BOOP_DELAY 750

// ---- Start Controls ----
#define startButtonPin 30    //the pin that the start button is attached to
#define startButtonLedPin 31 // the pin for start button LED
//TO DO: connect LED light

// ---- Player Controls ----

// Player 1 - Red
#define buttonPin 26    // the pin that the pushbutton is attached to
#define buttonLedPin 27 // the pin for button LED

// Player 2 - green
#define buttonPinTwo 22
#define buttonLedPinTwo 23

// ---- Lights ----

// int lightPins[] = {13, 12};
// const int lightPinsLength = sizeof(lightPins) / sizeof(int);

#define NUM_LEDS 300
#define LED_STRING_DATA_PIN 12

// Render player position
#define MAX_DISTANCE_TO_PLAYER 2.0

// Note: Milliamp value determined experimentally.
// - 3500mA works well if the 15A power supply is connected directly to one
//   end of the LED strip.
// - 1850mA works well if the LED strip is powered through breadboard and
//   jumper wires
#define LED_MAX_MILLIAMPS 1850

// ---- Game ----

#define MIN_PLAYER_POSITION 0
#define MAX_PLAYER_POSITION NUM_LEDS

#define PLAYER_VELOCITY_PICKUP 0.1
#define MAX_PLAYER_VELOCITY (32 * PLAYER_VELOCITY_PICKUP)

#define FRICTION .96

#define ON_POWER (IS_DEVELOPMENT ? 200 : 240)

#define GRAVITY_START 210
#define GRAVITY_AMOUNT 0.022

// ---- State Machine ----

#define STATE_NOT_LOADED -1
#define STATE_START_MENU 0
#define STATE_RESET_GAME 1
#define STATE_321_COUNTDOWN 2
#define STATE_GAMEPLAY 3
#define STATE_FINISH_LINE 4

// #endregion

// #region Global Variables

// ---- Sound ----
int lastBoopTime = 0;

SoftwareSerial mySoftwareSerial(10, 11); // RX, TX
DFRobotDFPlayerMini myDFPlayer;

// ---- Lights ----

CRGB leds[NUM_LEDS];

// ---- Game ----

unsigned int buttonPushCounter = 0; // counter for the number of button presses
byte playerButtonState = 0;         // current state of the button
byte lastPlayerButtonState = 0;     // previous state of the button
byte playerButtonStateTwo = 0;
byte lastPlayerButtonStateTwo = 0;

byte startButtonState = 0;                     // current state for start buttom
byte lastStartButtonState = 0;                 // previous state of start button
unsigned long lastStartButtonLedBlinkTime = 0; // previous state of led high/low

float playerPosition = 0;
float playerPositionTwo = 0;
float playerVelocity = 0;
float playerVelocityTwo = 0;

const CRGB playerColor = CRGB(200, 0, 0).fadeToBlackBy(IS_DEVELOPMENT ? 128 : 0);

// 2
const CRGB playerColorTwo = CRGB(9, 227, 67).fadeToBlackBy(IS_DEVELOPMENT ? 128 : 0);

CRGB *winnerColor;

// ---- State Machine ----
byte currentState = STATE_NOT_LOADED;

// #endregion

void setState(
    // input
    int newState)
{
  // logic
  int lastState = currentState;
  if (ENABLE_LOGS)
  {
    Serial.print("setState: newState= ");
    Serial.print(newState);
    Serial.print(" lastState= ");
    Serial.print(lastState);
    Serial.print("\n");
  }

  currentState = newState;

  // Transition between states

  // Transition FROM
  if (lastState == STATE_START_MENU)
  {
    transitionFromStartMenu();
  }

  // Transition TO
  if (currentState == STATE_321_COUNTDOWN)
  {
    transitionTo321Countdown();
  }
  else if (currentState == STATE_RESET_GAME)
  {
    transitionToResetGame();
  }
  else if (currentState == STATE_GAMEPLAY)
  {
    transitionToGameplay();
  }
  else if (currentState == STATE_FINISH_LINE)
  {
    transitionToFinishLine();
  }
}

void transitionToFinishLine()
{
}

void transitionFromStartMenu()
{
  digitalWrite(startButtonLedPin, LOW);
}

/** Auto transition to STATE_GAMEPLAY */
void transitionTo321Countdown()
{
  // Play sound
  myDFPlayer.playMp3Folder(MP3_START_SOUND);

  // Wait for start sound to end
  delay(1000);

  setState(STATE_GAMEPLAY);
}

void transitionToGameplay()
{
  FastLED.clear();
}

/**
 * Reset all gameplay related variables.
 * Auto transition to STATE_START_MENU
 */
void transitionToResetGame()
{
  // Reset player state
  buttonPushCounter = 0;
  playerButtonState = 0;
  lastPlayerButtonState = 0;
  playerButtonStateTwo = 0;
  lastPlayerButtonStateTwo = 0;

  startButtonState = 0;
  lastStartButtonState = 0;

  playerPosition = 0;
  playerPositionTwo = 0;
  playerVelocity = 0;
  playerVelocityTwo = 0;

  // Stop all audio
  myDFPlayer.pause(); //pause the mp3

  setState(STATE_321_COUNTDOWN);
}

void halt(const String &s)
{
  if (ENABLE_LOGS)
  {
    Serial.println("...Program halted...");
    Serial.println(s);
  }

  while (true)
  {
    delay(0); // Code to compatible with ESP8266 watch dog.
  }
}

void waitForMp3Connection()
{
  if (ENABLE_LOGS)
    Serial.print("\nInitializing DFPlayer ... (May take 3~5 seconds)\n");

  int connectionTryCount = 0;

  while (true)
  {
    connectionTryCount++;

    if (ENABLE_LOGS)
    {
      Serial.print("Attempting connection to MP3 player... connectionTryCount= ");
      Serial.print(connectionTryCount);
      Serial.print("\n");
    }

    bool isMp3PlayerConnected = myDFPlayer.begin(mySoftwareSerial);

    if (!isMp3PlayerConnected)
    { //Use softwareSerial to communicate with mp3.
      Serial.println("Unable to begin, connection to MP3 player failed:");
      Serial.println("1.Please recheck the connection!");
      Serial.println("2.Please insert the SD card!");

      Serial.println("Retrying...");
      delay(1000);
    }
    else
    {
      break;
    }
  }

  if (ENABLE_LOGS)
    Serial.println("DFPlayer Mini online.");
}
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
